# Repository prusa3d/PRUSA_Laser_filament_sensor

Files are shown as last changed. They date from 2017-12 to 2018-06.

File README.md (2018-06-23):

# PRUSA Laser filament sensor

Filament presence and velocity detection using a [PAT9125EL optical laser movement sensor](http://www.pixart.com.tw/product_data.asp?product_id=173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), operating at 850nm.

See also:
* [PAT9125EL datasheet](http://www.pixart.com/upload/PAT9125EL_GDS_V1.2_31052017_20171011150843.pdf)
* [boucaron's investigation into this board](https://steemit.com/printing3d/@boucaron/prusa-mk3-filament-detector-short-study)

# KiCad PCB layout
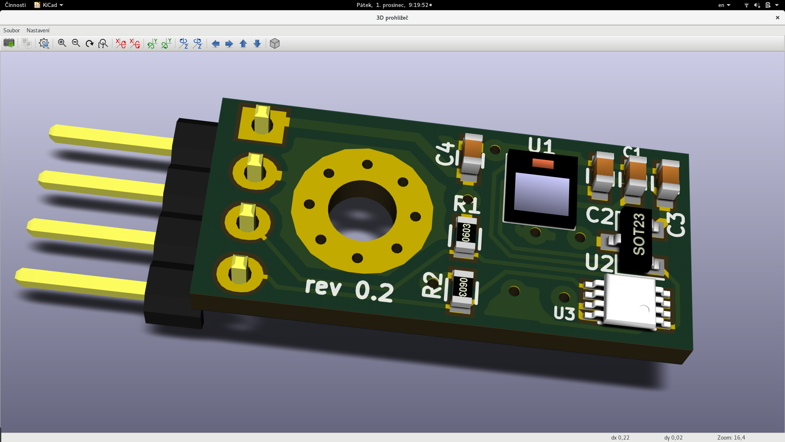
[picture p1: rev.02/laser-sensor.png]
PCB


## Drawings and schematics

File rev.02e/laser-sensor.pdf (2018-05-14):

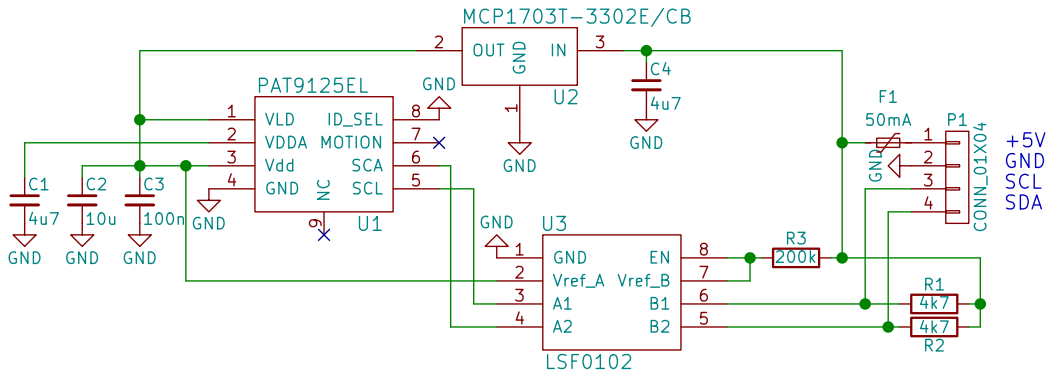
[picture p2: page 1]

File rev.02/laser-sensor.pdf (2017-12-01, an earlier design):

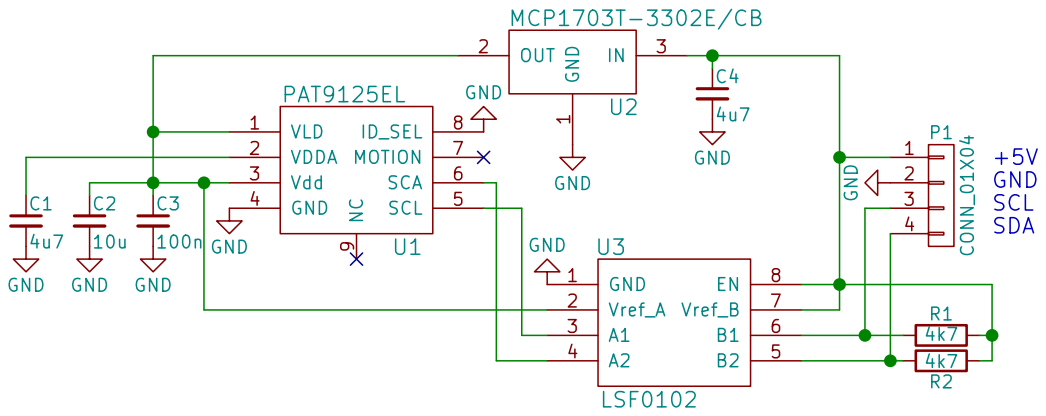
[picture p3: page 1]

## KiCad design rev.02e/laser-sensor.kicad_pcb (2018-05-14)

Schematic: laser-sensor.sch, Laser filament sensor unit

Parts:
C1, C4: 4u7; C_0603
C2: 10u; C_0603
C3: 100n; C_0603
F1: 50mA; R_1206
P1: CONN_01X04; Pin_Header_Angled_1x04
R1, R2: 4k7; R_0603
R3: 200k; R_0603
U1: PAT9125EL
U2: MCP1703T-3302E/CB; SOT-23
U3: LSF0102

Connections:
GND: C1.2, C2.2, C3.2, C4.2, P1.2, U1.4, U1.8, U2.1 (GND), U3.1
unnamed: C1.1, U1.2
unnamed: C2.1, C3.1, U1.1, U1.3, U2.2 (OUT), U3.2
unnamed: C4.1, F1.2, R1.2, R2.1, R3.2, U2.3 (IN)
unnamed: F1.1, P1.1
unnamed: P1.3, R1.1, U3.6
unnamed: P1.4, R2.2, U3.5
unnamed: R3.1, U3.7, U3.8
unnamed: U1.5, U3.3
unnamed: U1.6, U3.4

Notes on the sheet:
+5V GND SCL SDA

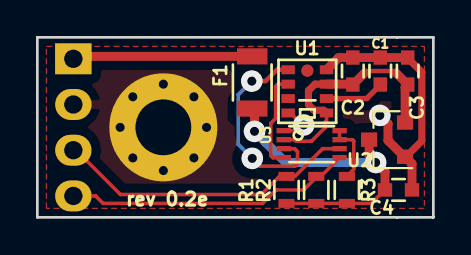
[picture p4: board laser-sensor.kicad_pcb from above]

Board: 2 copper layers, 22.0 x 10.0 mm, 12 parts (1 on the bottom side), 10 nets.

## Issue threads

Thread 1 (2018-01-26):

Add SPI pin and/or I2C select bridge

3d-gussner, 2018-01-26:
As Prusa is planning to have 5 filament runout sensors on the MK3 MMU wouldn't it make sense to:
- add a solder bridge from ID_SEL (pin 8 PAT9125EL) to GND and VDD (3 sensors could be active in I2C mode at the same time)
  -  closed to VDD = HIGH I2C Slave ID (7-bit) 0x73
  -  closed to GND = LOW I2C Slave ID (7-bit) 0x75
  -  open = NC I2C Slave ID (7-bit) 0x79
- add additional PIN (ID_SEL) to the MMU stepper switch to use the PAT9125EL in SPI mode

Why don't use the MOTION pin 7 to detect "simple" motion?

ok1hra, 2018-01-26:
Because motion pin provides too little information

3d-gussner, 2018-01-27:
@ok1hra Thanks for the info. I
Can you tell me what i am doing wrong opening the KiCad schematics i get:
The following libraries were not found:
 - \home\dan\kicad\hra\lib\ok1hra

ok1hra, 2018-01-31:
Yes, this in the past use libraries you do not need, the used parts are inserted.

Closed 2018-01-31.

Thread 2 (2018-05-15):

Missing filter cap on LSF0102 Vref.

tjhawkey, 2018-05-15:
The 200k resistor from the datasheet is now included, but I think you are still missing a cap from vref to ground.
The data sheet says this (but doesn't recommend a specific cap value)
A filter capacitor on Vref_B is recommended.

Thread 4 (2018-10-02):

Version 0.2 can catch fire, should be removed from the repository!

gregsaun, 2018-10-02:
Lots of people reported that the version 0.2 can catch fire, this version should be removed from the repository immediately!

https://shop.prusa3d.com/forum/general-discussion-announcements-and-releases-f69/be-aware-the-filament-sensor-almost-caught-fire--t24590.html
https://shop.prusa3d.com/forum/others-archive--f66/filament-sensor-just-burned-up--t14394.html
https://www.facebook.com/groups/prusacommunity/permalink/857264271280973/

You should also make a campaign to replace the older version. Please take this seriously!
